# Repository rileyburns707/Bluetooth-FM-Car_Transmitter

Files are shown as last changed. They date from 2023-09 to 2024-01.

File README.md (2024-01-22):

# Bluetooth-FM-Car_Transmitter
This is every step I took to create a Bluetooth FM car transmitter so I could play music in my car. I started from nothing and worked through basic ideas of how it would work, the parts I would need, breadboarding it, and soldering it.

Overview:
Have a PCB that connects the BM20 chip and NS73M chip. Designed that PCB on Eagle.
Then connect M5StickC+ to PCB and program M5 using Arduino code

I will explain briefly what is needed for this project:

List of important things
- NS73M - FM transmitter
- BM20 - Bluetooth chip
- M5StickC+
- Cigarette lighter with USB-C
- PCB for NS73M for breadboard. Found one on OSH Park 
- PCB for BM20 for breadboard. Found one on OSH Park
- PCB for Bluetooth FM Transmitter. I created the PCB for this using Eagle. Everything for that PCB is in the "Eagle" file
- Arduino code. Code for the M5StickC+. Everything for that is in the "Arduino code" file
- Capacitor "EEE-FK1A560SR" from Digi-key
- Crystal "R26-32.768-12.5" from Digi-key
- Switch mode DC:DC converter "OKI-78SR-3.3/1.5-W36H-C" from Digi-key

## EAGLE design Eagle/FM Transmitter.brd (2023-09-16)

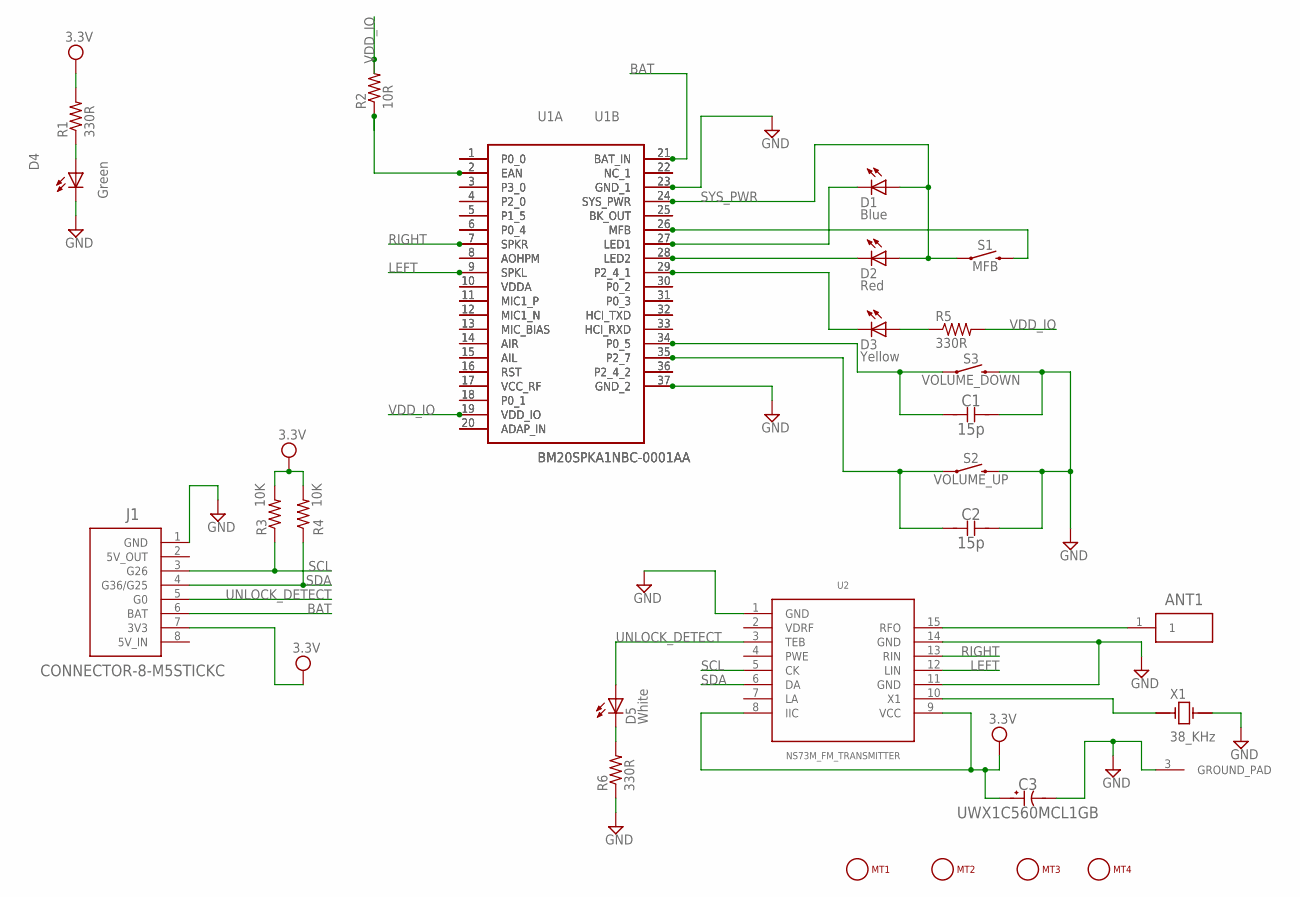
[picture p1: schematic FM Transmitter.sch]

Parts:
ANT1: CONNECTOR-1; ESQ-101-XX-X-S
C1, C2: 15p; CAPC2012X140N
C3: UWX1C560MCL1GB; PCAP_6.3X5.4-ELECT-M
D1: Blue; LED5MM
D2: Red; LED5MM
D3: Yellow; LED5MM
D4: Green; LED5MM
D5: White; LED5MM
J1: CONNECTOR-8-M5STICKC; ESQ-108-XX-X-S
MT1, MT2, MT3, MT4: MOUNTING_HOLE-125_250_ROUND; MT_125_250
R1, R5, R6: 330R; R0805
R2: 10R; R0805
R3, R4: 10K; R0805
S1: MFB; TACTILE_SWITCH_PTH_6.0MM
S2: VOLUME_UP; TACTILE_SWITCH_PTH_6.0MM
S3: VOLUME_DOWN; TACTILE_SWITCH_PTH_6.0MM
U1A, U1B: BM20SPKA1NBC-0001AA; BM20SPKA1NBC0001AA
U2: NS73M_FM_TRANSMITTER; NS73M
X1: 38_KHz; XTAL-WITH-GROUND-PAD

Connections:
3.3V: C3.1, J1.7 (3V3), R1.2, R3.2, R4.2, U2.8 (IIC), U2.9 (VCC)
BAT: J1.6 (BAT), U1A.21 (BAT_IN), U1B.21 (BAT_IN)
GND: C1.2, C2.2, C3.2, D4.K (C), J1.1 (GND), R6.1, S2.3 (2), S3.3 (2), U1A.23 (GND_1), U1A.37 (GND_2), U1B.23 (GND_1), U1B.37 (GND_2), U2.1 (GND), U2.11 (GND), U2.14 (GND), X1.2, X1.3 (GROUND_PAD)
LEFT: U1A.9 (SPKL), U1B.9 (SPKL), U2.12 (LIN)
unnamed: ANT1.1, U2.15 (RFO)
unnamed: D4.A, R1.1
unnamed: R2.1, U1A.2 (EAN), U1B.2 (EAN)
unnamed: D3.K (C), U1A.29 (P2_4_1), U1B.29 (P2_4_1)
unnamed: D2.K (C), U1A.28 (LED2), U1B.28 (LED2)
unnamed: D1.K (C), U1A.27 (LED1), U1B.27 (LED1)
unnamed: D3.A, R5.1
unnamed: D5.K (C), R6.2
unnamed: S1.3 (2), U1A.26 (MFB), U1B.26 (MFB)
unnamed: U2.10 (X1), X1.1
unnamed: C2.1, S2.1, U1A.35 (P2_7), U1B.35 (P2_7)
unnamed: C1.1, S3.1, U1A.34 (P0_5), U1B.34 (P0_5)
unnamed: U1A.1 (P0_0), U1B.1 (P0_0)
unnamed: U1A.3 (P3_0), U1B.3 (P3_0)
unnamed: U1A.4 (P2_0), U1B.4 (P2_0)
unnamed: U1A.5 (P1_5), U1B.5 (P1_5)
unnamed: U1A.6 (P0_4), U1B.6 (P0_4)
unnamed: U1A.8 (AOHPM), U1B.8 (AOHPM)
unnamed: U1A.10 (VDDA), U1B.10 (VDDA)
unnamed: U1A.11 (MIC1_P), U1B.11 (MIC1_P)
unnamed: U1A.12 (MIC1_N), U1B.12 (MIC1_N)
unnamed: U1A.13 (MIC_BIAS), U1B.13 (MIC_BIAS)
unnamed: U1A.14 (AIR), U1B.14 (AIR)
unnamed: U1A.15 (AIL), U1B.15 (AIL)
unnamed: U1A.16 (RST), U1B.16 (RST)
unnamed: U1A.17 (VCC_RF), U1B.17 (VCC_RF)
unnamed: U1A.18 (P0_1), U1B.18 (P0_1)
unnamed: U1A.20 (ADAP_IN), U1B.20 (ADAP_IN)
unnamed: U1A.22 (NC_1), U1B.22 (NC_1)
unnamed: U1A.25 (BK_OUT), U1B.25 (BK_OUT)
unnamed: U1A.30 (P0_2), U1B.30 (P0_2)
unnamed: U1A.31 (P0_3), U1B.31 (P0_3)
unnamed: U1A.32 (HCI_TXD), U1B.32 (HCI_TXD)
unnamed: U1A.33 (HCI_RXD), U1B.33 (HCI_RXD)
unnamed: U1A.36 (P2_4_2), U1B.36 (P2_4_2)
RIGHT: U1A.7 (SPKR), U1B.7 (SPKR), U2.13 (RIN)
SCL: J1.3 (G26), R3.1, U2.5 (CK)
SDA: J1.4 (G36/G25), R4.1, U2.6 (DA)
SYS_PWR: D1.A, D2.A, S1.1, U1A.24 (SYS_PWR), U1B.24 (SYS_PWR)
UNLOCK_DETECT: D5.A, J1.5 (G0), U2.3 (TEB)
VDD_IO: R2.2, R5.2, U1A.19 (VDD_IO), U1B.19 (VDD_IO)

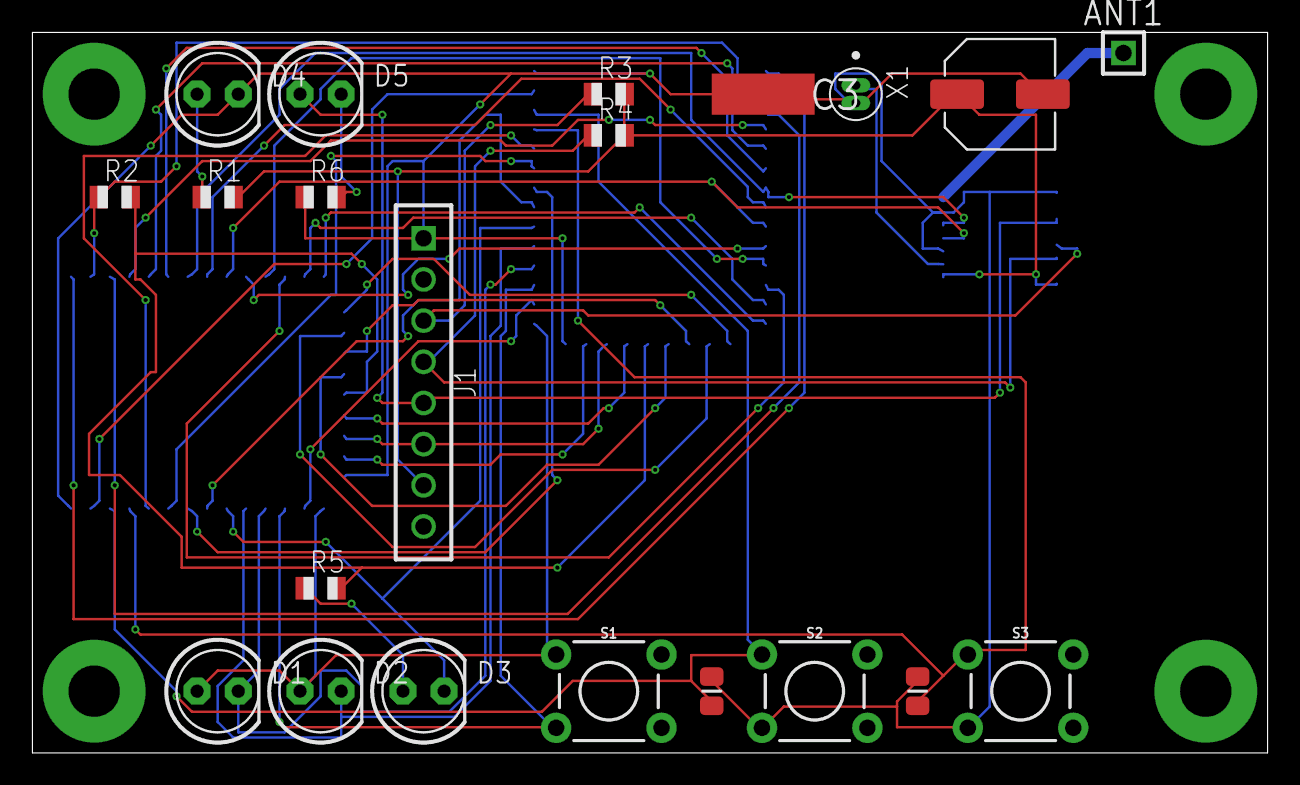
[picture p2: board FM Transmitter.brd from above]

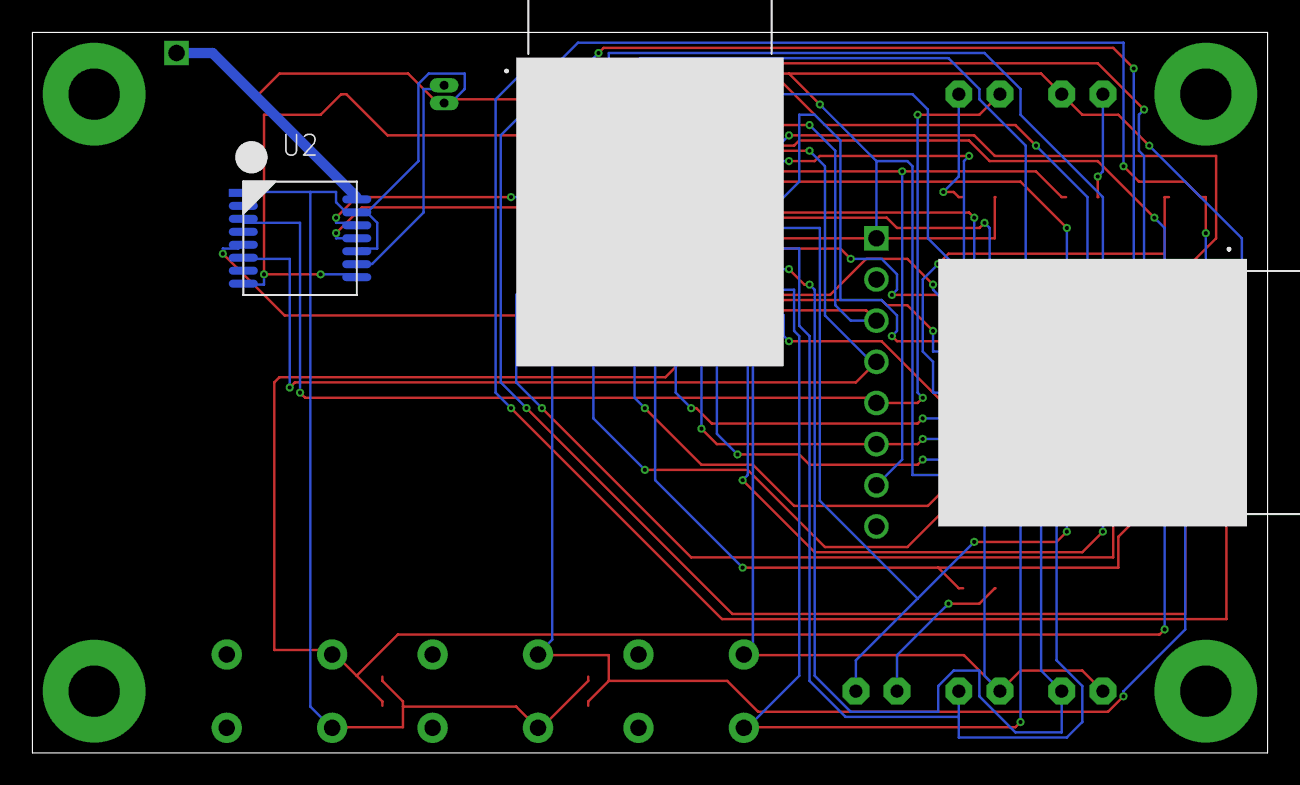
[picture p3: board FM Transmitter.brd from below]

Board: 2 copper layers, 76.2 x 44.5 mm, 27 parts (3 on the bottom side), 45 nets.
